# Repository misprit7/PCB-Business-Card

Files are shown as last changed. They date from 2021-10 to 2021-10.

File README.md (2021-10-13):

<h1 align="center">
  <br />
  PCB Business Card
</h1>

This is my custom PCB business card. At the end of 2020 I wanted a project to learn more about the principles of PCB design, so I decided to make a fully custom PCB that functions both as a microcontroller and as a business card. It has the following functionality: 

- Fully programmable microcontroller compatible with and Arduino bootloader (although SWD flashing is required first)
- Bluetooth communication
- NFC capabilities with just one chip being soldered on to enable my website to be pulled up just by tapping the PCB to a phone
- UART, SPI and analog/digital outputs through standard pin headers
- Easily powered through micro USB
- 5 LEDs to indicate power/digitally toggle
- One power switch, one input switch and an input pushbutton

The final product looks like this: 

https://user-images.githubusercontent.com/33139843/137082818-c895b24c-45d9-431c-9933-9b9995591427.mp4

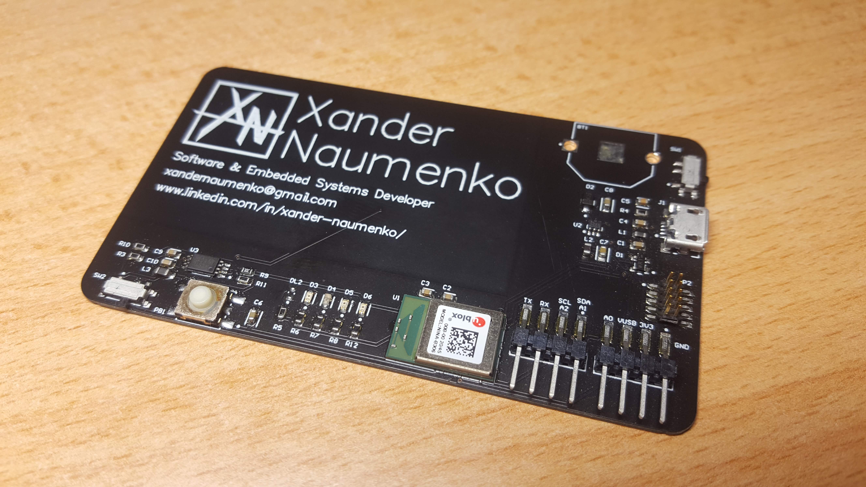
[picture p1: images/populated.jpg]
business card

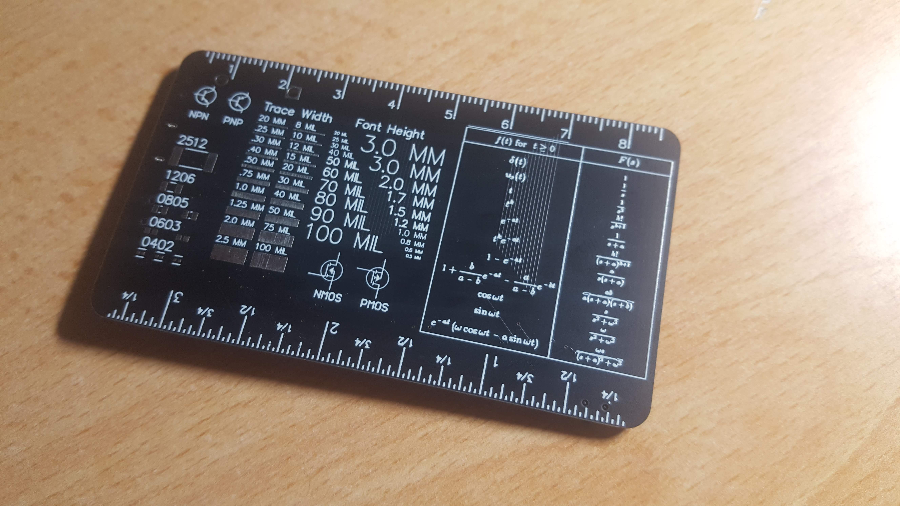
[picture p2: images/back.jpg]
card back

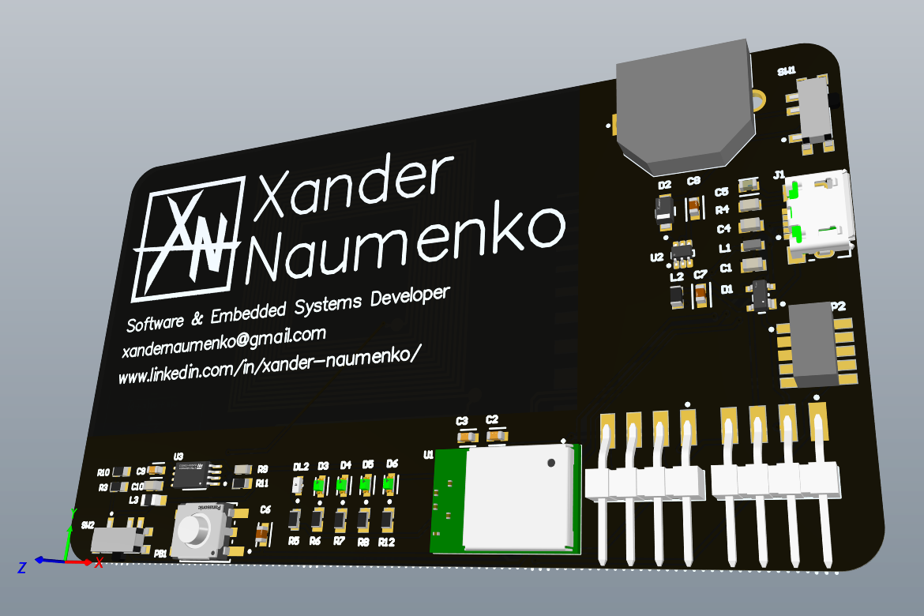
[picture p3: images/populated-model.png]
business card model


I used Altium to design the board. A lot of it was a learning experience so some aspects of the design probably don't follow best practices, but I'm very happy with how the design turned out. This is the schematic and x-ray view of the board: 

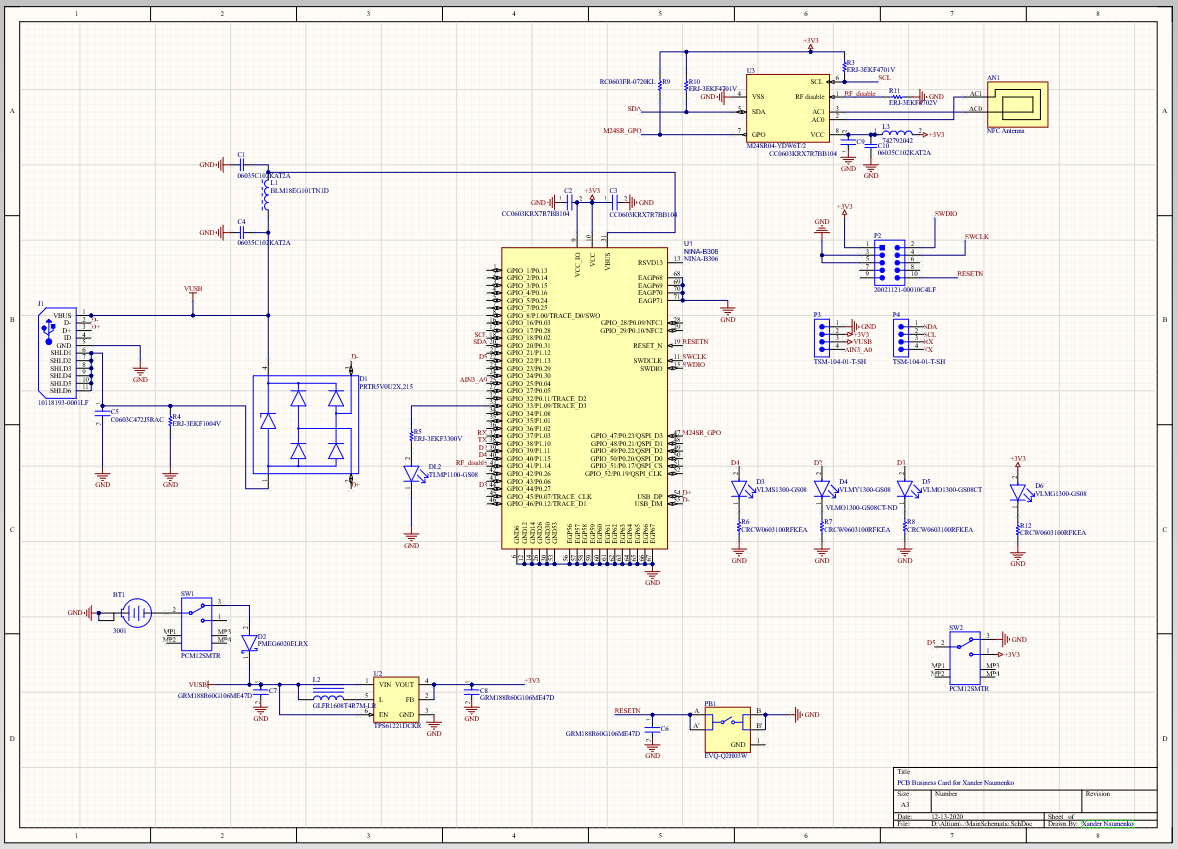
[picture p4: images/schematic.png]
schematic

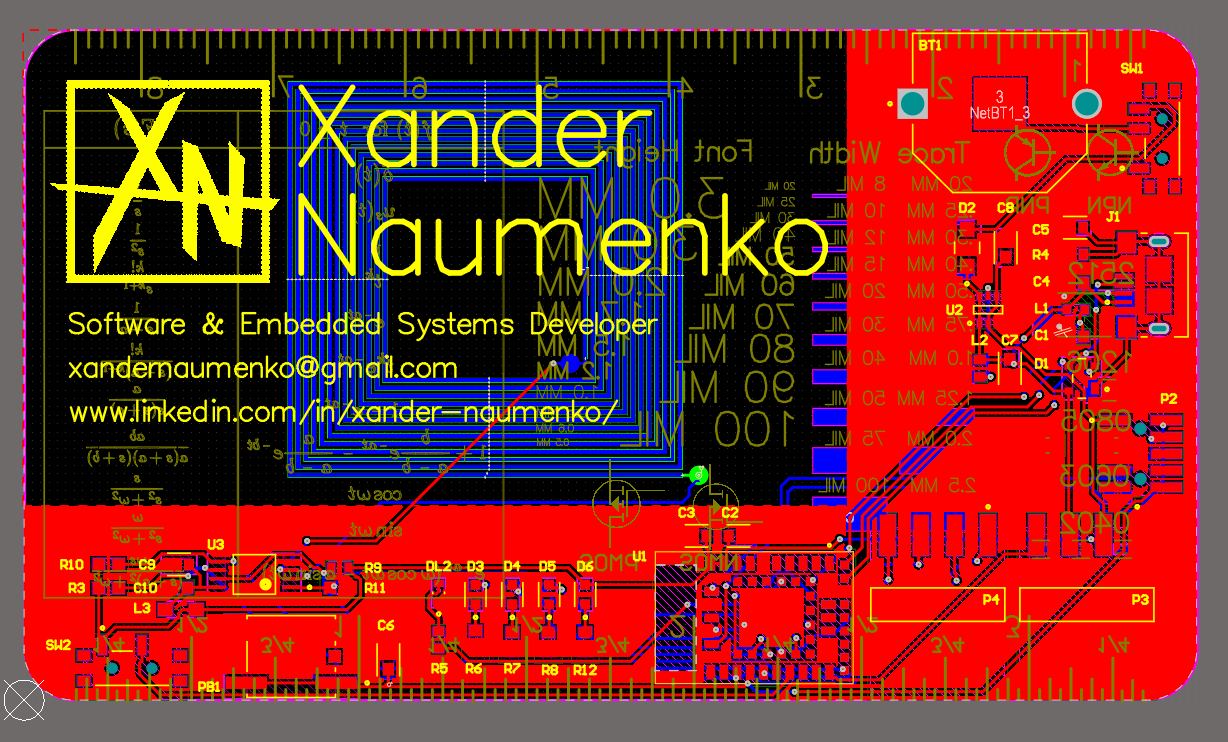
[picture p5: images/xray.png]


After it was designed, I ordered all the necessary components and physically built the board using a reflow oven. The first attempt version was shorted due to a misaligned chip (in hindsight I definitely should have avoided hand placing a BGA MCU), but the the second attempt at soldering worked and the MCU can successfully be programmed. 

## Issues

If anyone wants to make a similar PCB or even use this design while just changing the silkscreen, here are some problems with what's currently on Github. 

1. The Battery is way underspecced. I misinterpreted a datasheet and as such the battery can't provide enough current for the MCU. To fix this would probably required moving some layout around to fit a bigger battery. Right now that just means that the PCB can only be powered through USB which works fine. 

2. The font on the back for the table of Laplace transforms was printed weird. That might just be an issue on JLCPCB's side but as it is there are some random lines slightly out of place and the equations aren't super readable. This is just aesthetic though and doesn't affect anything electrically. 

## Credits

The Antenna design was almost directly used from [here](https://github.com/badrbouslikhin/Enchante), a very similar and really cool project that I would highly recommend you check out. 

The circuit design was heavily influenced by the [Arduino Nano BLE](https://store-usa.arduino.cc/products/arduino-nano-33-ble), as I used the same chip and wanted to maintain compatibility with the Arduino.

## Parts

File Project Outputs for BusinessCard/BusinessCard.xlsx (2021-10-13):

Comment | Description | Designator | Footprint | LibRef | Quantity
NFC Antenna | L=5.51 uH, tuned for 13.56 MHz | AN1 | NFC_Antenna | NFC_Antenna | 1
3001 | Holder Battery Coin, 12 mm, 2-Pin THD, RoHS | BT1 | KSTN-3001_V | CMP-2000-05463-1 | 1
06035C102KAT2A |  | C1, C4, C10 | CAPC1608X90X35LL15T15 | CMP-2006-04378-1 | 3
CC0603KRX7R7BB104 | CAP CER 0.1UF 16V X7R 0603 | C2, C3, C9 | FP-CC0603-DA-MFG | CMP-2000-05002-2 | 3
C0603C472J5RAC | C0603 4,700 pF X7R 30ppm/°C 5.00% 50 V | C5 | FP-C0603C-CF-MFG | CMP-03020-004543-2 | 1
GRM188R60G106ME47D | Chip Multilayer Ceramic Capacitors for General Purpose, 0603, 10uF, X5R, 15%, 20%, 4V | C6, C7, C8 | FP-GRM188-0_1-e0_2_0_55-IPC_B | CMP-2006-02787-5 | 3
PRTR5V0U2X,215 | TVS DIODE 5.5V SOT143B | D1 | FP-SOT143B-MFG | CMP-14436-000007-1 | 1
PMEG6020ELRX | DIODE SCHOTTKY 60V 2A SOD123W | D2 | FP-SOD123W-MFG | CMP-14398-000020-1 | 1
VLMS1300-GS08 | LED RED 0603 SMD | D3 | FP-6_541-5092_01-4-MFG | CMP-02520-000012-1 | 1
VLMY1300-GS08 | LED YELLOW 0603 SMD | D4 | FP-6_541-5092_01-4-MFG | CMP-02520-000001-1 | 1
VLMO1300-GS08CT | LED YELLOW 0603 SMD | D5 | FP-6_541-5092_01-4-MFG | CMP-02520-000001-1 | 1
VLMG1300-GS08 | LED GREEN 0603 SMD | D6 | FP-6_541-5092_01-4-MFG | CMP-02520-000011-1 | 1
TLMP1100-GS08 | LED GREEN 0603 SMD | DL2 | FP-6_541-5056_01-4-MFG | CMP-02520-000009-1 | 1
10118193-0001LF | Micro USB B Type Receptacle, -55 to 85 degC, 5-Pin SMD, RoHS, Tape and Reel | J1 | FCI-10118193-0001LF-5_V | CMP-2000-05119-1 | 1
BLM18EG101TN1D | Chip Ferrite Bead for GHz Band General Use (Low DC Resistance Type), 100 Ohm, 2000 mA, -55 to 125 degC, 1.6 x 0.8 x 0.65 mm SMD, Tape and Reel | L1 | MURA-BLM18-RF-H3-CHIP-2_V | CMP-0686-00530-2 | 1
GLFR1608T4R7M-LR | Chip Inductor, 4.7 uH, +/- 20%, -40 to 105 degC, 0603 (1608 Metric), RoHS, Tape and Reel | L2 | INDC1608X100X35LL20T15 | CMP-2000-06322-1 | 1
742792042 | SMD EMI Suppression Ferrite Bead WE-CBF, Z = 600 Ohm | L3 | SMD-0805 | CMP-0220-00097-1 | 1
20021121-00010C4LF | Male Header, Pitch 1.27 mm, 2 x 5 Position, Height 4.55 mm, -40 to 85 degC, RoHS, Tape and Reel | P2 | HDR2X5_SMT | CMP-2000-05523-1 | 1
TSM-104-01-T-SH | 0.025" SQ Post Header, Surface Mount, Horizontal, -55 to 105 degC, 2.54 mm Pitch, 4-Pin, Male, RoHS | P3, P4 | SMTC-TSM-104-01-X-SH | CMP-1024-00223-1 | 2
EVQ-Q2H03W | SWITCH TACTILE SPST-NO 0.02A 15V | PB1 | FP-EVQ-Q2H03W-MFG | CMP-05618-000002-1 | 1
ERJ-3EKF4701V | Precision Thick Film Chip Resistor, 4.7 KOhm, +/- 1%, -55 to 155 degC, 0603 (1608 Metric), RoHS, Tape and Reel | R3, R10 | RESC1608X55X30NL15T15 | CMP-1012-00586-3 | 2
ERJ-3EKF1004V |  | R4 | RESC1608X55X30LL15T15 | CMP-1012-00849-2 | 1
ERJ-3EKF3300V | Chip Resistor, 330 Ohm, +/- 1%, 0.1 W, -55 to 155 degC, 0603 (1608 Metric), RoHS, Tape and Reel | R5 | RESC1608X55X30LL15T15 | CMP-2000-00435-2 | 1
CRCW0603100RFKEA | Chip Resistor, 100 Ohm, +/- 1%, 100 mW,-55 to 155 degC, 0603 (1608 Metric), RoHS, Tape and Ree | R6, R7, R8, R12 | RESC1609X50X30ML8T20 | CMP-2000-03824-5 | 4
RC0603FR-0720KL | Chip Resistor, 20 KOhm, +/- 1%, 0.1 W, -55 to 155 degC, 0603 (1608 Metric), RoHS, Tape and Reel | R9 | RESC1608X55X25LL10T15 | CMP-2000-06932-1 | 1
ERJ-3EKF4702V | Chip Resistor, 47 KOhm, +/- 1%, 0.1 W, -55 to 155 degC, 0603 (1608 Metric), RoHS, Tape and Reel | R11 | RESC1608X55X30NL15T15 | CMP-2000-00523-2 | 1
PCM12SMTR | Ultraminiature Slide Switch, SPDT, 0.3 A, 6 V, -20 to 85 degC, 3-Pin SMD, RoHS, Tape and Reel | SW1, SW2 | CKCP-PCM12SMTR_V | CMP-2000-06884-1 | 2
NINA-B306 | Stand-alone Bluetooth low energy module | U1 | NINA_LGA71R_1500X1000X223_PCB | NINA-B306 | 1
TPS61221DCKR | Boost Voltage Converter with 0.7 to 5.5 V Input and 3.3 V Output, -40 to 85 degC, 6-Pin SC70 (DCK), Green (RoHS & no Sb/Br) | U2 | DCK0006A_L | CMP-0343-00082-2 | 1
M24SR04-YDW6T/2 | IC RFID TRANSP 13.56MHZ 8TSSOP | U3 | FP-TSSOP8-AM-IPC_C | CMP-12160-000009-1 | 1

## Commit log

2020-12-11 Added Microcontroller parts
    [MainPCB.PcbDoc, MainSchematic.SchDoc]
2020-12-14 Finished routing and designing front and back silkscreen
    [BusinessCard.xlsx, MainSchematic.SchDoc]
2020-12-23 Added pin names
    [BusinessCard.PrjPcb, MainSchematic.SchDoc]
2021-10-12 Updated gitignore
    [BusinessCard.PrjPcb, BusinessCard.xlsx]
2021-10-13 Updated readme with video
    [BusinessCard.PrjPcb, BusinessCard.xlsx]
